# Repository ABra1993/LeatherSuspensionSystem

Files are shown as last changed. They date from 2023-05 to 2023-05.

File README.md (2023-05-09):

# Modular gravity-based suspension system for gilt leather wall hangings
This repository is included in a paper named:  "Modular gravity-based suspension system for gilt leather wall hangings", published in september 2023 by ICOM-CC and contains information about the suspension system, including detailed drawings as well as data that has been collected, describing the behaviour of the leather over a period of a year.

The suspension and monitoring system is open access and distributed under the terms of the CC BY-SA 4.0 license. https://creativecommons.org/licenses/by-sa/4.0/

Structure
------------
This repository contains the following directories:

* **materials_suppliers**: 14 detailed drawings (in DXF-format) of the mounting system, including size and dimensions. More information about the mounting system and files can be found in the directory (info.pdf).

* **data**: file (.csv) containing data describing the behaviour of wall hangings mounted on the suspension system in the Regentessenkamer at Voormalig Weeshuis Enkhuizen, including the displacement of the leather (in horizontal and vertical direction), as well as temperature and relative humidity.

* **scripts**: custom scripts written in Python. One script can be used to extract the information in the .csv file (located in the **data** directory) and convert it to a Pandas dataframe (read_data.py). The other two scripts reproduce Figure 7 (fig7_mm.py) and Figure 8 (fig8_40perc.py) as presented in Brands et al. (2023), visualizing the relation between the displacement of the leather over time and the relative humidity. 

* **plots**: files containing the outputs from the custom scripts used to visualize the data (file names correspond to the names of the custom scripts in the **scripts** directory that produce them).

## Installation
Clone the git repository to create a local copy with the following command:

    $ git clone git@github.com:ABra1993/LeatherSuspensionSystem.git

Supplementary info
------------
Additional information about the data analysis can be found here:
https://docs.google.com/document/d/1wCsgwAU4O0nHiB8O62IX6cypKUmrL2wZS21t7bLyCXc/edit#

Disclaimer
------------
We have made every attempt to ensure the accuracy and reliability of the information provided on this website. However, the information provided is “as is” without warranty of any kind. We do not accept any responsibility or liability for the accuracy, content, completeness, legality, or reliability of the information contained on this repository.

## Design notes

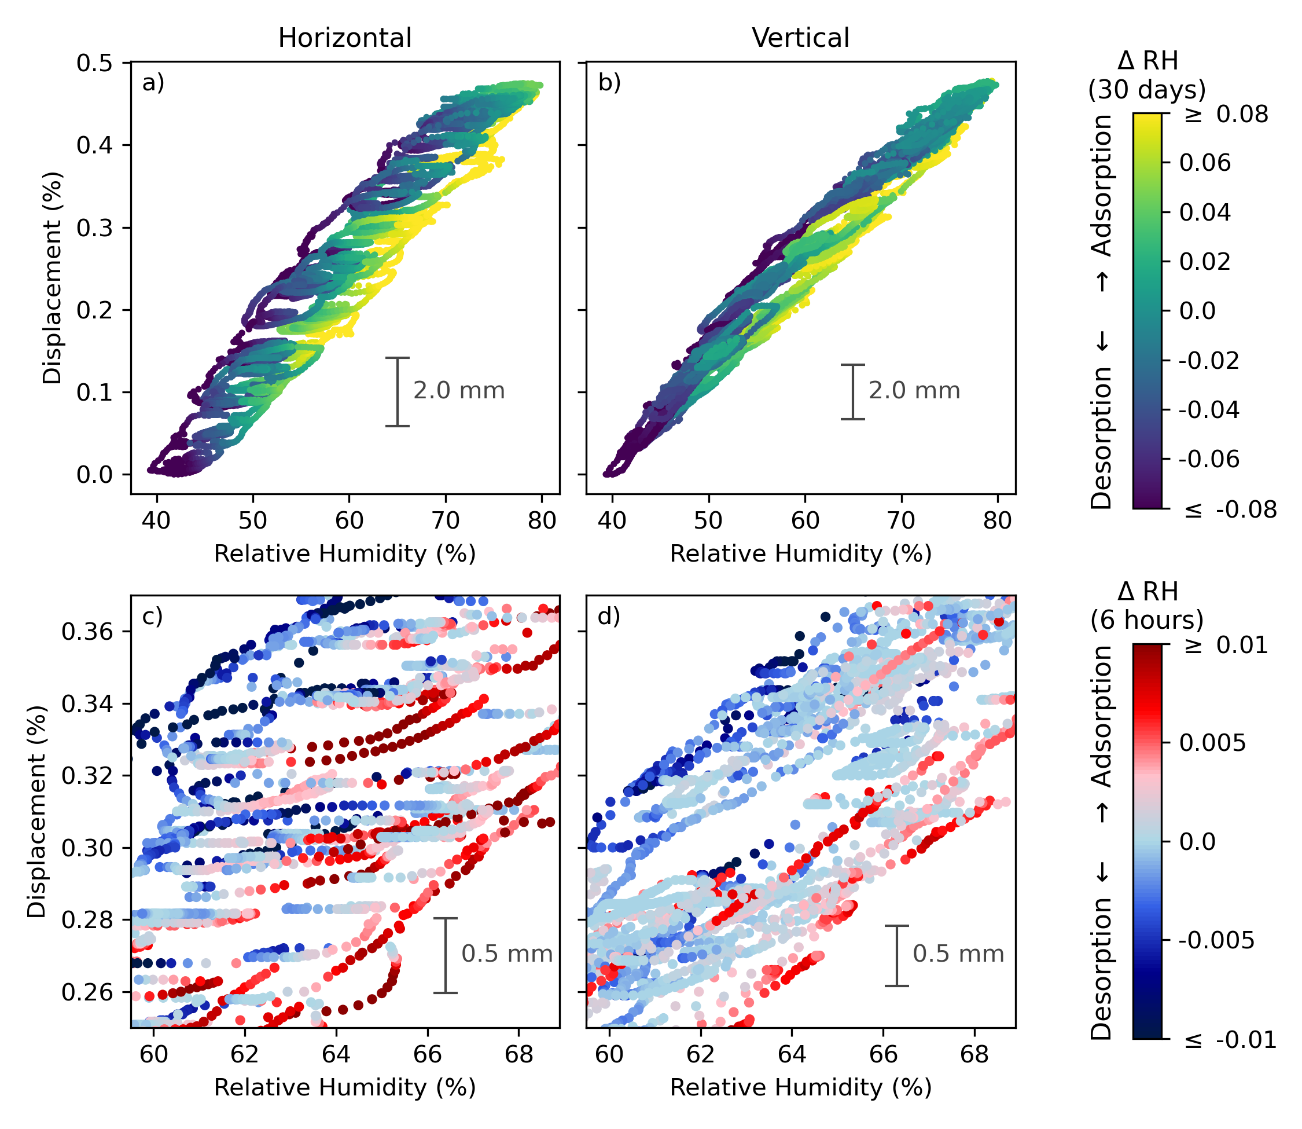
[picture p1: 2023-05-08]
plots/fig8_perc_mm.png

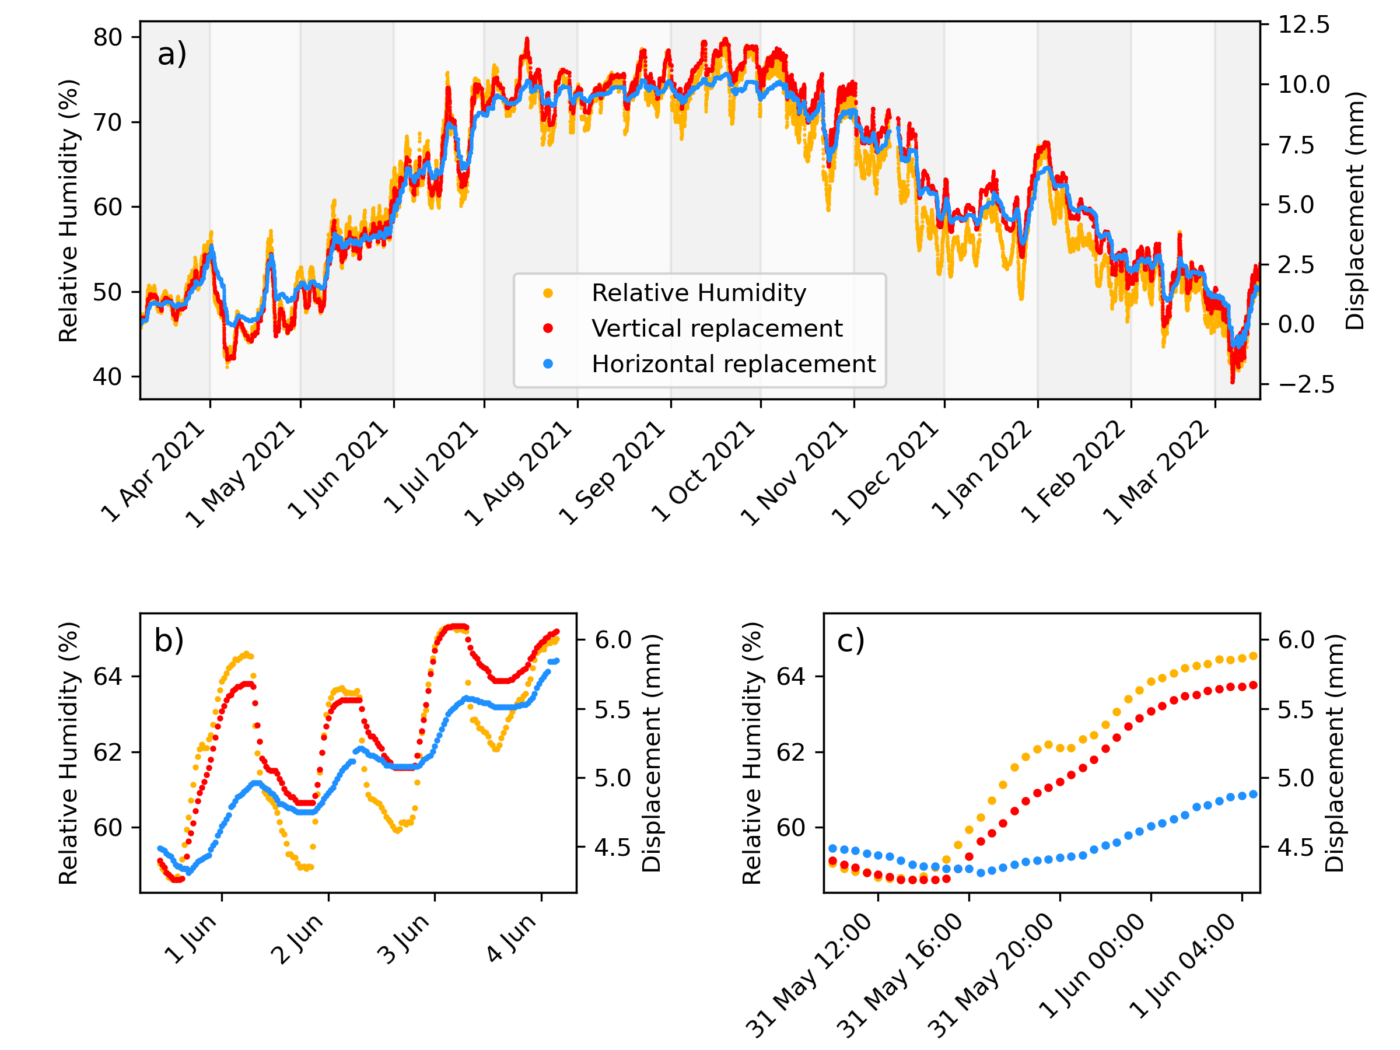
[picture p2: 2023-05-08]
plots/fig7_mm.png

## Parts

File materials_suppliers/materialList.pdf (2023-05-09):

Material list
Trade name | website
Velcro | https://www.strapryte.com/
BEVA®371 film 65 mm | https://www.labshop.nl/
3D Mesh tissue | https://fr.aliexpress.com/item/32635759392.html
Polymax high tack | https://www.griffonfrance.fr/fr
Rivet art 5901153010 | https://rivet-expert.com/nl
Vanadium steel bearing | https://fr.aliexpress.com/item/32823685825.html
Controller customized | https://yens-yens.nl/
SHAHE 150 mm Caliper | https://nl.aliexpress.com/item/32817482308.html
DHT22 T&RH sensor | https://nl.aliexpress.com/item/32890356257.html
For stainless steel laser cut parts: | https://www.247tailorsteel.com/nl

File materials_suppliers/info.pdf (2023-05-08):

The suspension system consists of 4 different modules, composed by 11 different parts. 3 additional parts are needed to mount the system to the wall.

You can download the individual drawings of the parts in DXF-format for communication with the cutting factory.
A separate drawing has been made of each part, attached in DXF format. All 14 parts have to laser cut in various numbers from stainless steel plate of either 1 or 2 mm thickness, as indicated in the names.

List of parts:

left-frame | top- | right-frame

Bottomframe all over

name of laser part

number of
parts for
mod 1

number of
parts for
mod 2

number of
parts for
mod 3

number of
parts for
mod 4

total
number for
1 set
1 mounting plate | | 1 | 1
2 velcro-bar horizontal | 1 | 1 | 2
3 stilt support | 2 | | 2
4 stabilizer | | 2 | 2
5 velcro-bar vertical | 1 | 1 | 2
6 side bar | 1 | 1 | 2
7 center bar | 1 | 1 | 2
8 balance bar | 2 | 2 | 4
9 rail | | 1 | 1
10 weight | | 1 | 1
11 washer | 32
as
needed 19
additional parts
12 brackets | 16
| | | minmal number

13 pulley base

as
needed

14 pulley top

as
needed

The drawings named 'pulley top' and 'pulley base' depict components of pulleys to be assembled (not visible on the assembly drawing).

One drawing has been made on which the entire suspension system is drawn and on which the names of the 11 composing parts are stated: see “assembly & identification drawing.pdf”

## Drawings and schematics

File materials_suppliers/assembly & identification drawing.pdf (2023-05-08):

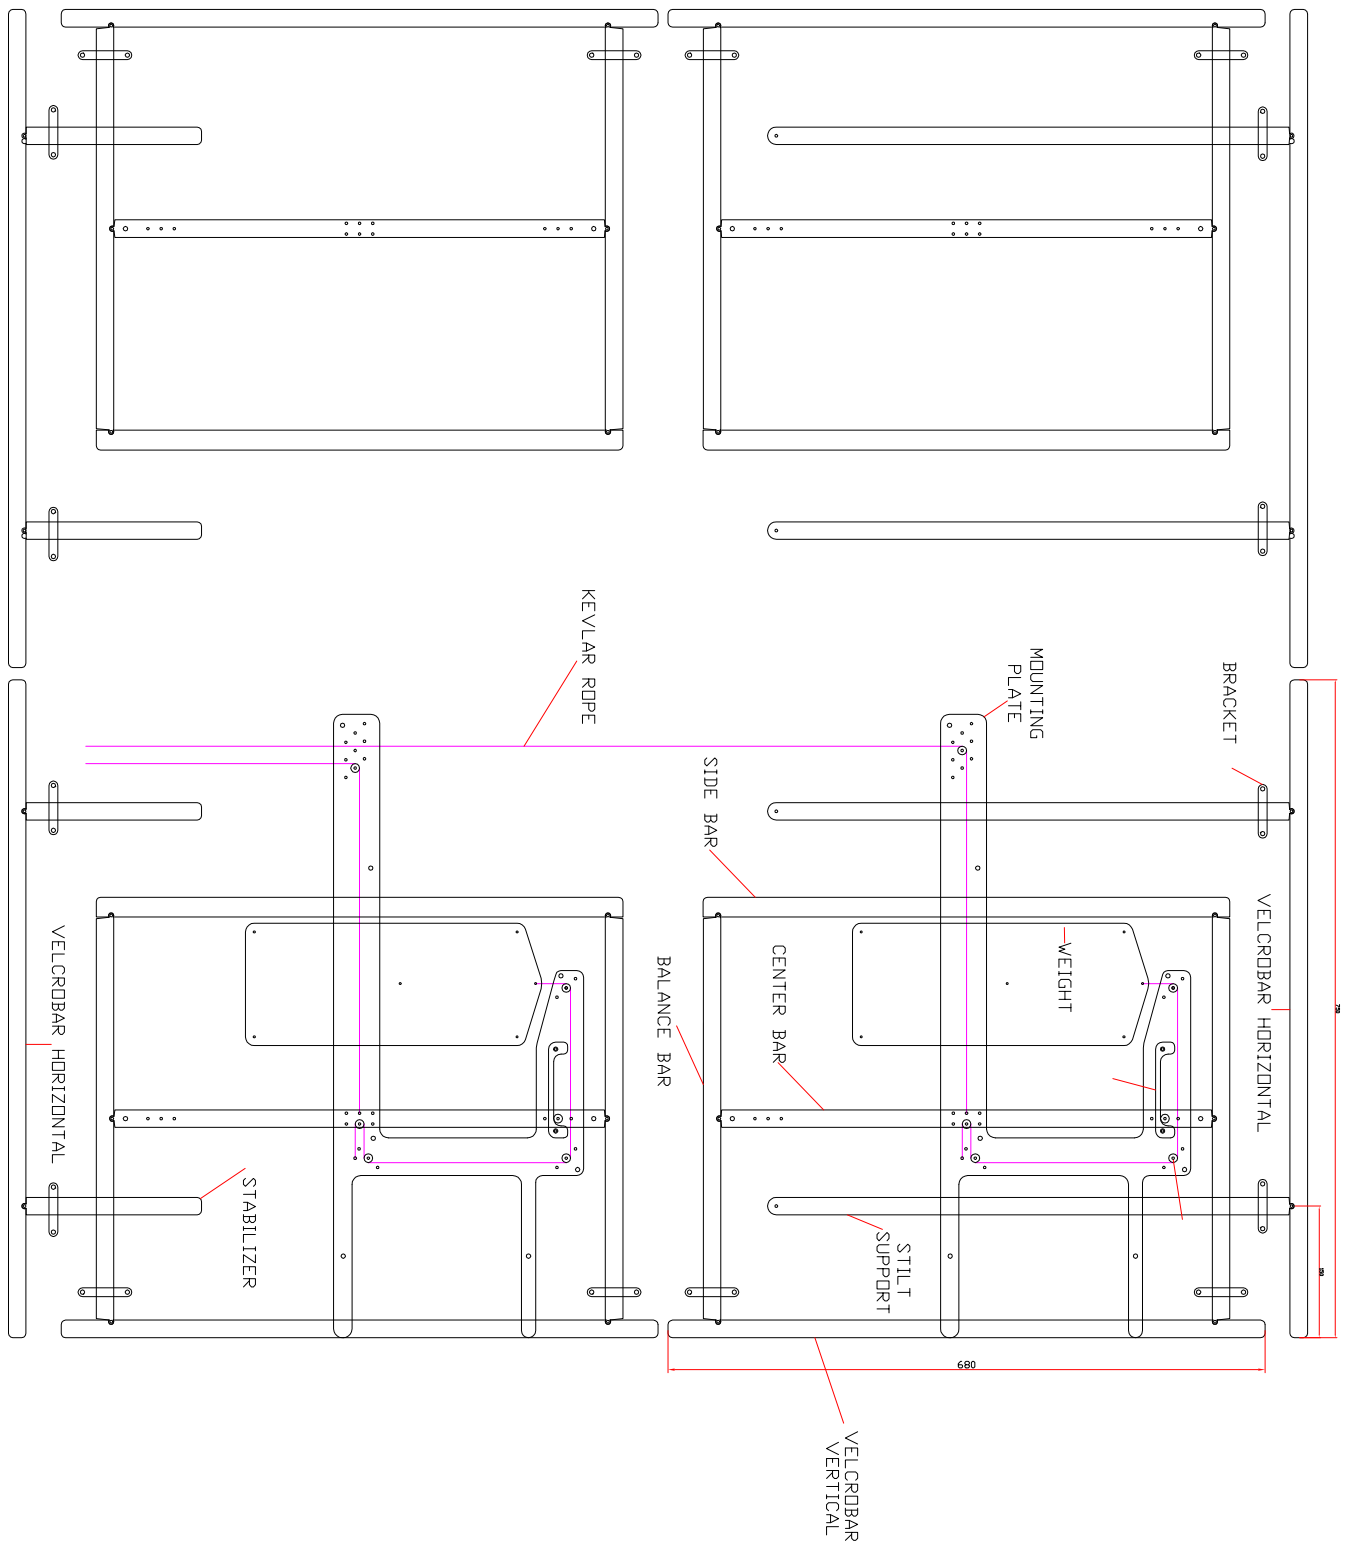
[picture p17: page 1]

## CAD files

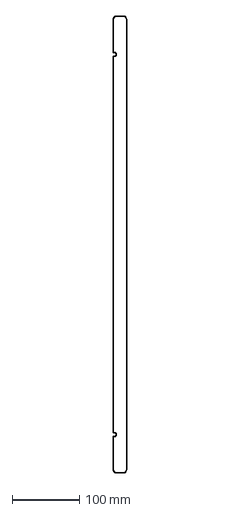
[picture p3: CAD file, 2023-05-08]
materials_suppliers/2mm VELCRO BAR VERTICAL.dxf
20.0 x 680.0 mm

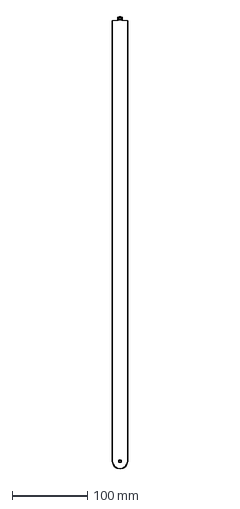
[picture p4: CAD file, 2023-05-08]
materials_suppliers/2mm STILT SUPPORT.dxf
19.9 x 600.2 mm

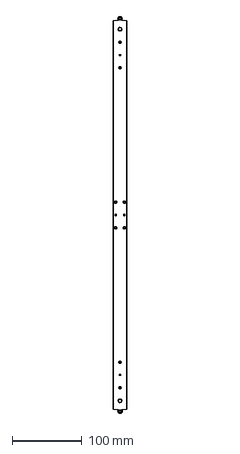
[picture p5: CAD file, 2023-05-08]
materials_suppliers/2mm CENTER BAR.dxf
20.0 x 570.1 mm

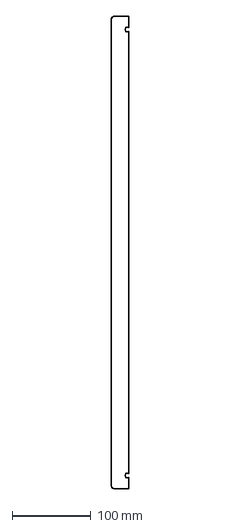
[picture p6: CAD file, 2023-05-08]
materials_suppliers/2mm SIDE BAR.dxf
22.6 x 600.0 mm

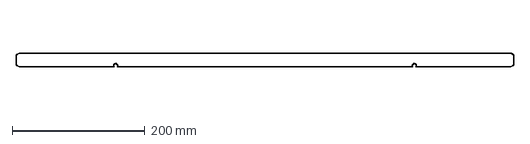
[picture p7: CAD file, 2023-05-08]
materials_suppliers/2mm VELCRO BAR HORIZONTAL.dxf
750.0 x 20.0 mm

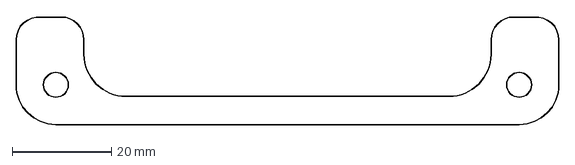
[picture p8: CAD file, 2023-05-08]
materials_suppliers/1mm RAIL.dxf
109.3 x 21.8 mm

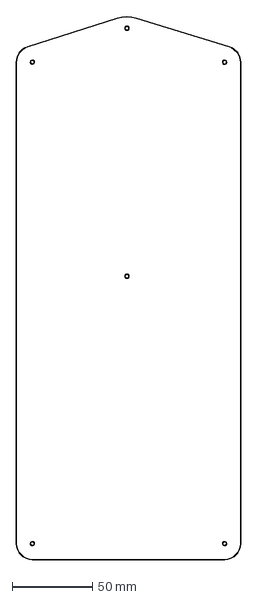
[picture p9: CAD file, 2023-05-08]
materials_suppliers/1mm WEIGHT.dxf
139.5 x 338.0 mm

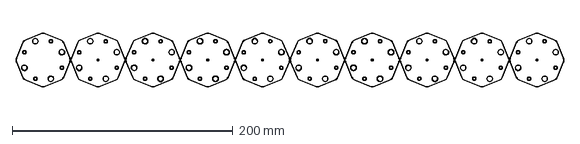
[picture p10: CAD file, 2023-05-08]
materials_suppliers/1 mm PULLEY BASE.dxf
495.7 x 49.0 mm

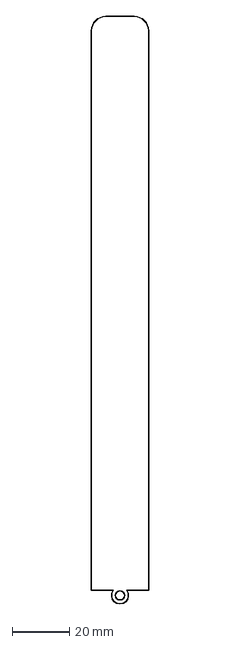
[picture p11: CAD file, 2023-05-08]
materials_suppliers/1mm STABILIZER.dxf
19.9 x 204.9 mm

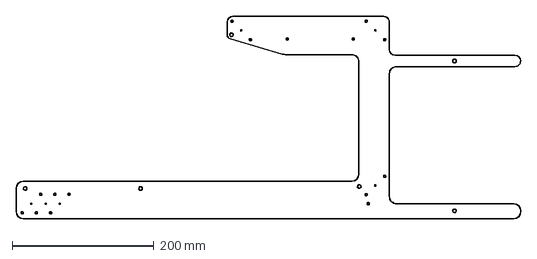
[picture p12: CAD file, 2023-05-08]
materials_suppliers/1mm MOUNTING PLATE.dxf
710.4 x 284.8 mm

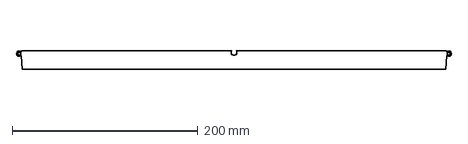
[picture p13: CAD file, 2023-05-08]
materials_suppliers/2mm BALANCE BAR.dxf
469.4 x 20.2 mm

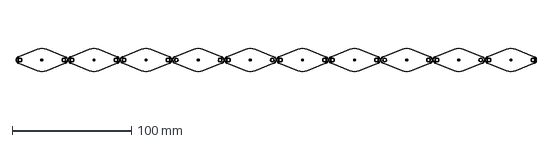
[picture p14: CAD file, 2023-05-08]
materials_suppliers/1 mm PULLEY TOP.dxf
436.1 x 20.1 mm

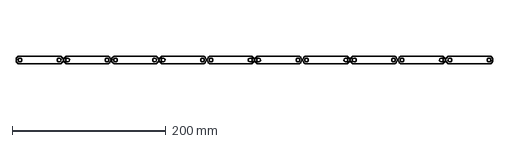
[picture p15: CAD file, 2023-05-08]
materials_suppliers/1mm BRACKET.dxf
620.1 x 10.0 mm

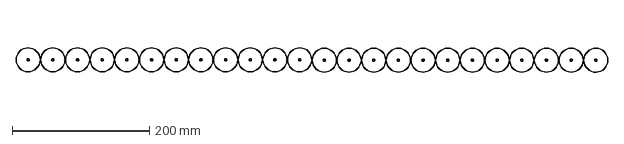
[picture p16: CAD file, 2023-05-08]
materials_suppliers/1 mm WASHER.dxf
863.0 x 35.9 mm
